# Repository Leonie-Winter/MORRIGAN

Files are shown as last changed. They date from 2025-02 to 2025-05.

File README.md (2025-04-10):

# MORRIGAN
--- 
## What is Morrigan?

Morrigan stands for 
- **M**obile
- **O**ptimized
- **R**eal-time
- **R**essource 
- **I**nterface
- **G**auge
- **A**nalysis
- **N**etwork

and aims to be a simple-to-use device based on the Raspberry Pi 3 to determine the quality of water using sensors from Gravity.

It measures the `total dissolved solids (TDS)(that are conductive), the dissolved oxygen (DO), the temperature, the pH, and the Turbidity`

---
You will find a build log in the [wiki](https://github.com/Leonie-Winter/MORRIGAN/wiki/build_log)[WIP] to find out how to get started

`/src` includes all files for the actual code and `/models` which includes a custom pcb design and a 3d case

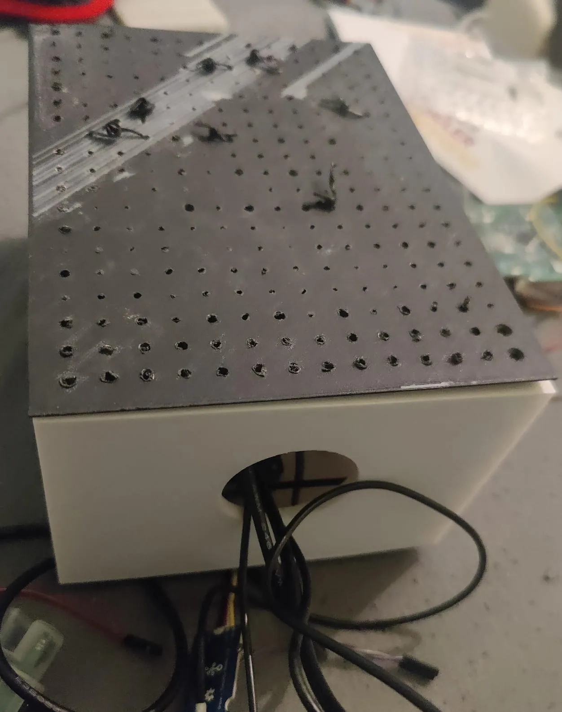
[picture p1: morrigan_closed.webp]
closed 3d shell
 &nbsp;&nbsp;&nbsp;&nbsp;&nbsp;
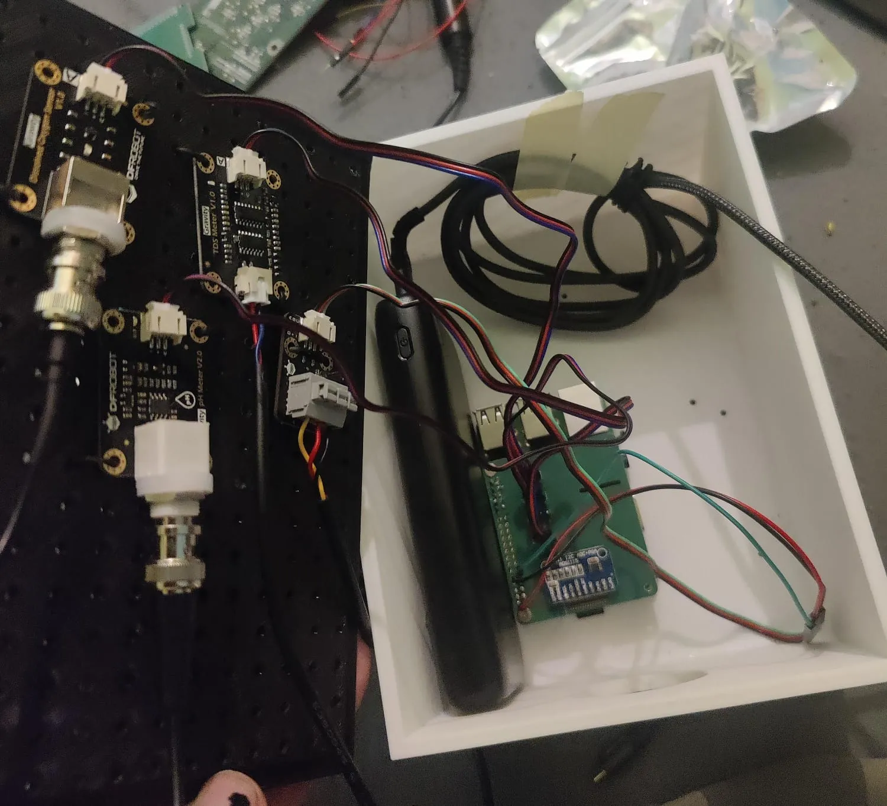
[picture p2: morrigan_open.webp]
open box showing some pcbs


--- 

If you are interested in thins such as previous competitions,the costs, and how it works check out the [wiki](https://github.com/Leonie-Winter/MORRIGAN/wiki/)

---

**This project was funded by the Erasmus+ program of the European Union.**
Funded by the European Union. Views and opinions expressed are however those of the author(s) only and do not necessarily reflect those of the European Union or the European Education and Culture Executive Agency (EACEA). Neither the European Union nor EACEA can be held responsible for them.
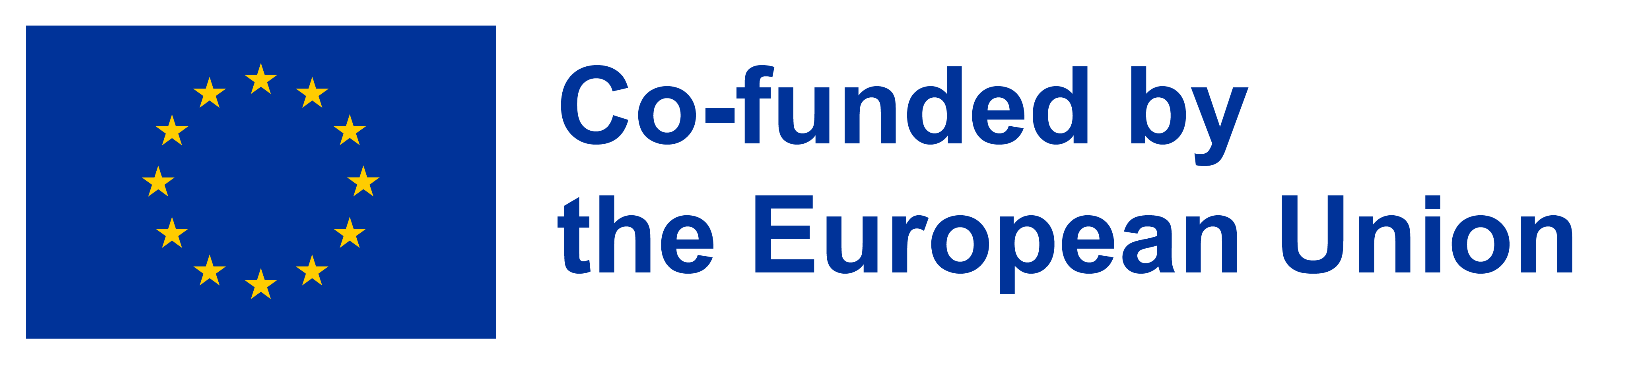
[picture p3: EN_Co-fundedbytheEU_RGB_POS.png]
co-funded by the european union logo


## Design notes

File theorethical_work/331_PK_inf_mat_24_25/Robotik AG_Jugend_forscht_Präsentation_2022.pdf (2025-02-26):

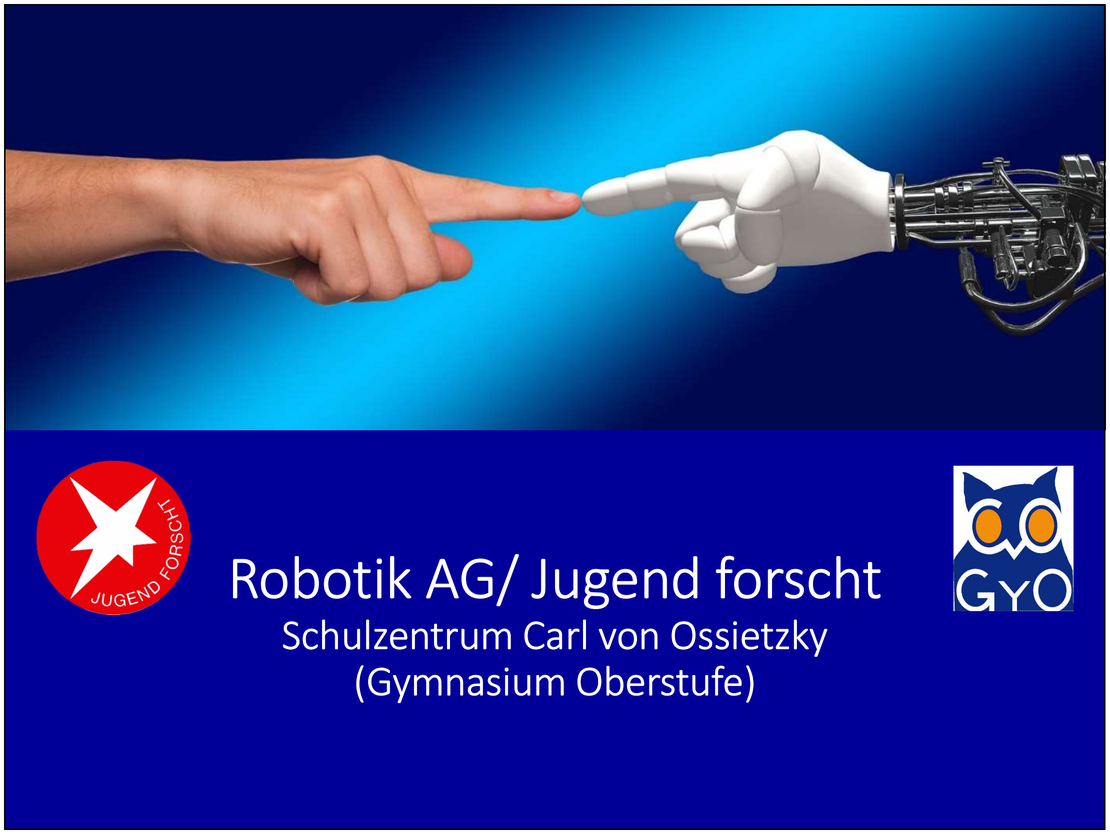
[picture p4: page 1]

Robotik AG am CvO | 03.09.2022 | Folie 1

## Robotik AG/ Jugend forscht

Schulzentrum Carl von Ossietzky (Gymnasium Oberstufe)

Robotik AG am CvO | 03.09.2022 | Folie 2

Robotik AG / Jugend forscht

## Wer wir sind

- ein erfahrenes Team, bestehend aus 3 KollegInnen
- Wir betreuen auch SchülerInnen beim Wettbewerb Jugend forscht bzw. Schüler experimentieren
- Die AG besteht seit 2010
- Sie findet freitags von 14:00 Uhr bis 17:30 statt

Kontakt:
Katja Pertlicsek: k.pertlicsek@schulen.bremerhaven.de Wolfram Bajus: w.bajus@schulen.bremerhaven.de

Wir sind auch über itslearning erreichbar!

Robotik AG am CvO | 03.09.2022 | Folie 3

Robotik AG

## Was wir anbieten

•Hilfe bei der Umsetzung eigener kleinerer technischer Projekte
•Unterstützung bei
der Planung, dem Bau, der Programmierung von Prototypen
technischen Projekten für Jugend forscht & Schüler experimentieren
•Arbeiten mit neuen Technologien 3D-Druckern, CNC-Portal-Fräsen
- Beratung und Erfahrungsaustausch

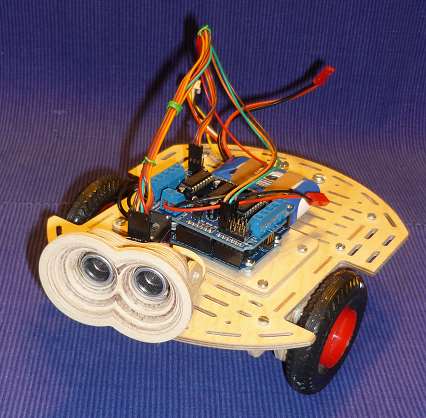
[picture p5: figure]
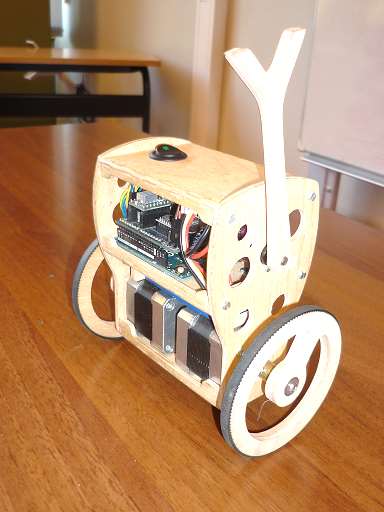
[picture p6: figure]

Robotik AG am CvO | 03.09.2022 | Folie 4

Robotik AG - Projektbeispiele

## Smartcars und balancierende Roboter

autonom fahrende,
Hindernis-vermeidende,
alternativ fernsteuerbare
Roboter

mit dem Smartphone
steuerbare Roboter

https://www.youtube.com/watch?v=ZSbpil-hHrE

## Laufroboter

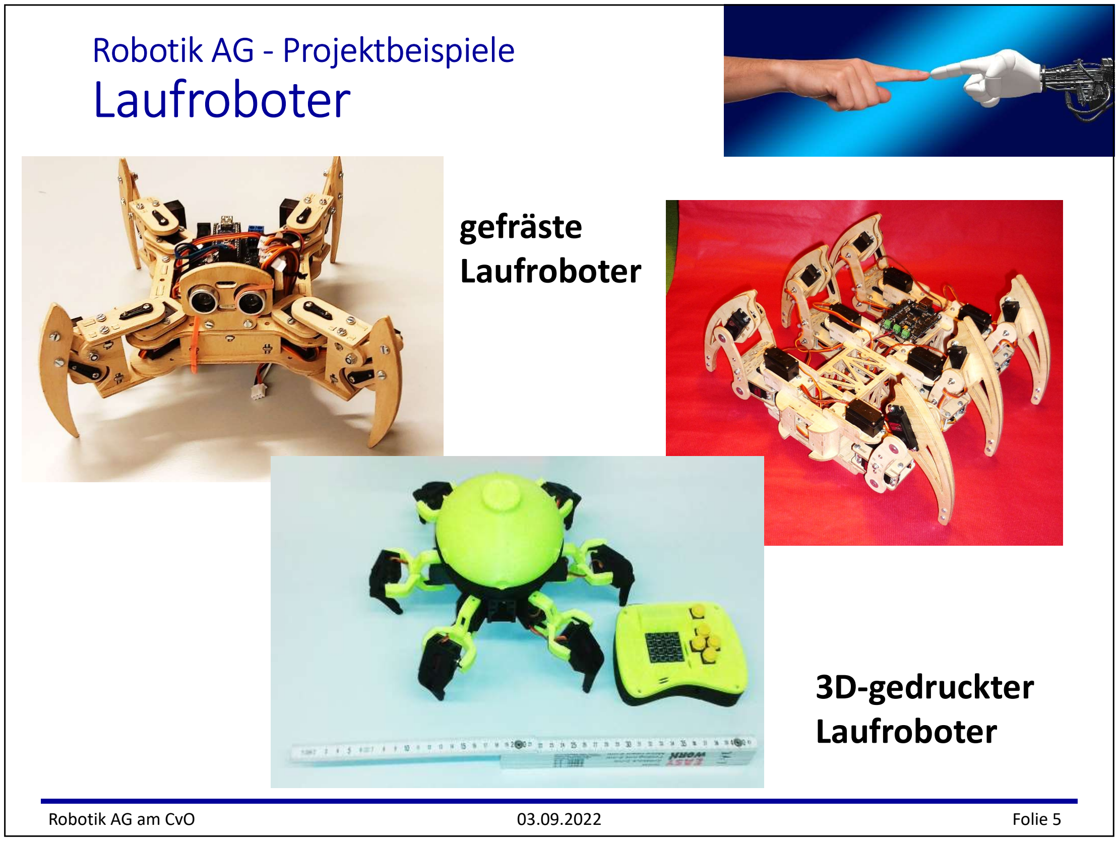
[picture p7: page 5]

Robotik AG am CvO | 03.09.2022 | Folie 5

Robotik AG - Projektbeispiele

gefräste
Laufroboter

3D-gedruckter
Laufroboter

## Ball balancierende Roboter

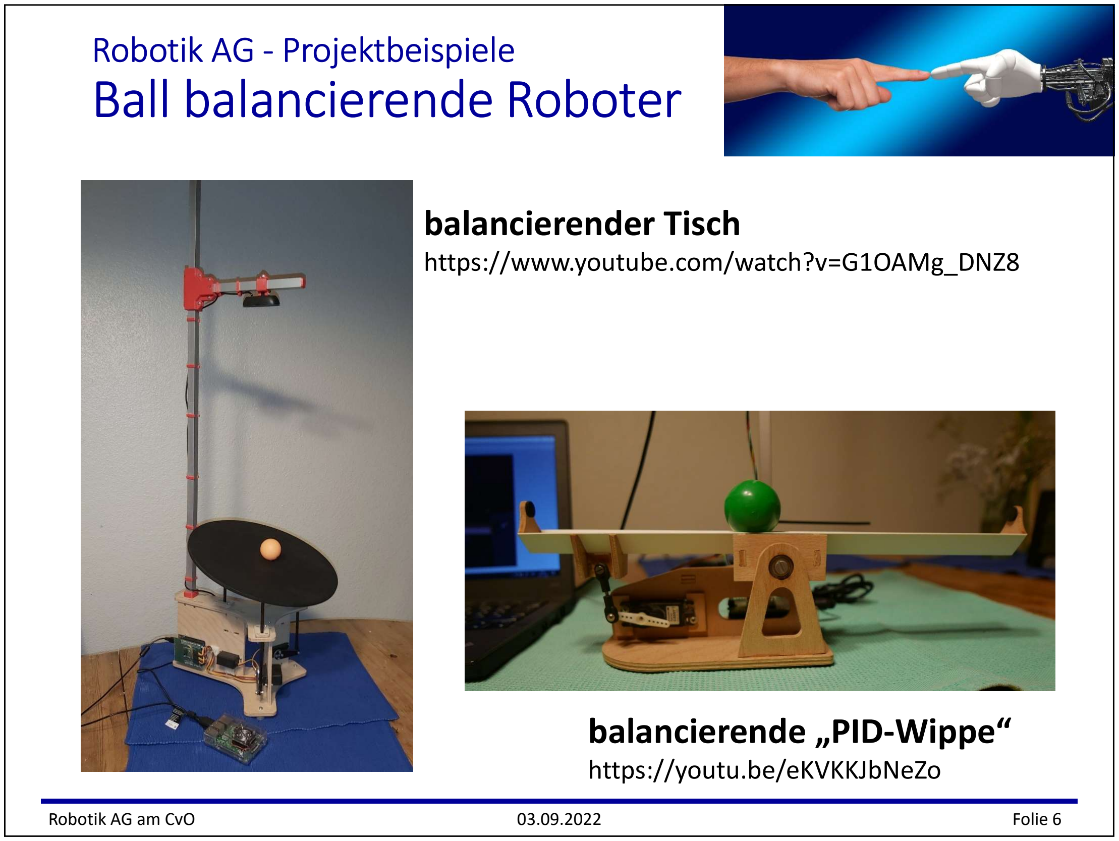
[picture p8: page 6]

Robotik AG am CvO | 03.09.2022 | Folie 6

Robotik AG - Projektbeispiele

balancierender Tisch
https://www.youtube.com/watch?v=G1OAMg_DNZ8

balancierende „PID-Wippe“
https://youtu.be/eKVKKJbNeZo

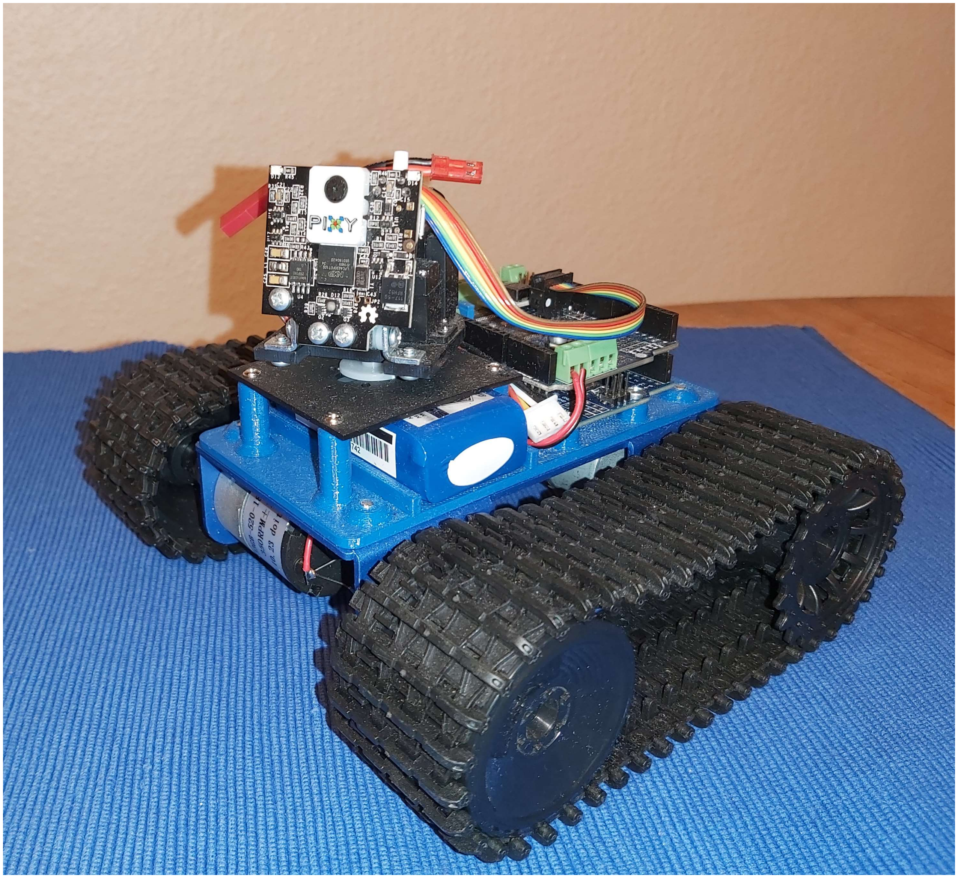
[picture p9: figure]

Robotik AG am CvO | 03.09.2022 | Folie 7

Robotik AG - Projektbeispiele

## Ball Chasing Robot

https://www.youtube.com/watch?v=rsmS00CuOFE

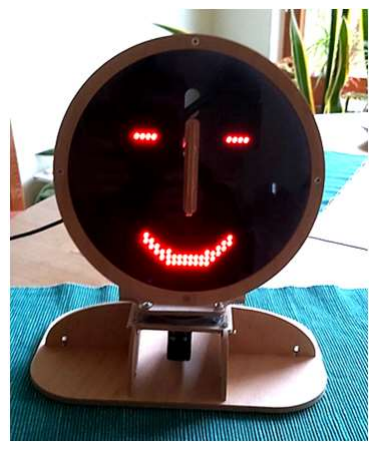
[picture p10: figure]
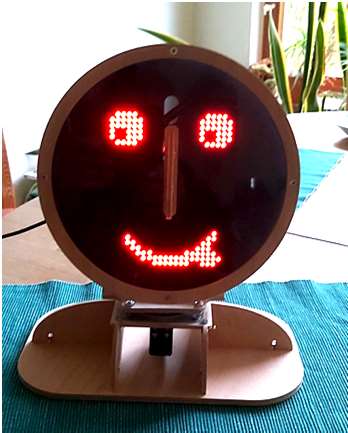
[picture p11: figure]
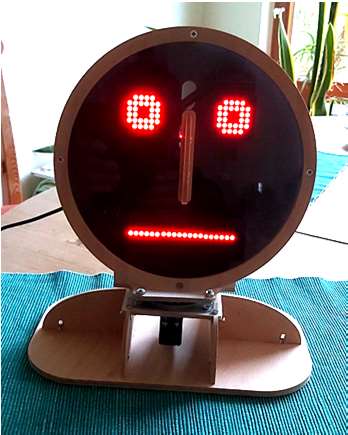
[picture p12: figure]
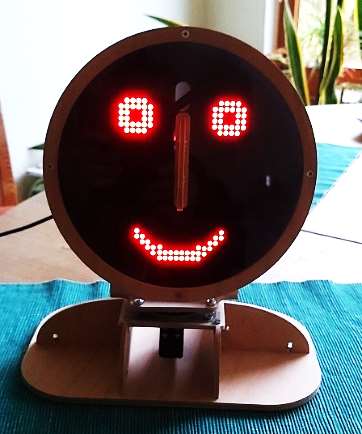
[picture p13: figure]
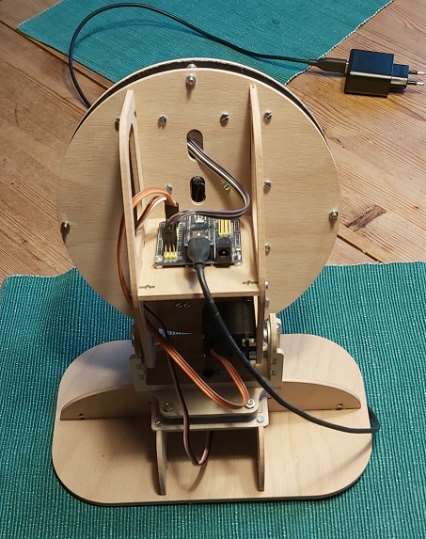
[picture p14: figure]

Robotik AG am CvO | 03.09.2022 | Folie 8

Robotik AG - Projektbeispiel

## Roboterkopf

Es braucht nur wenige Merkmale, damit wir Gesichter und
Emotionen darin erkennen.

Wenige Programmzeilen genügen, um dem Roboter neue
Gesichtsausdrücke beizubringen.

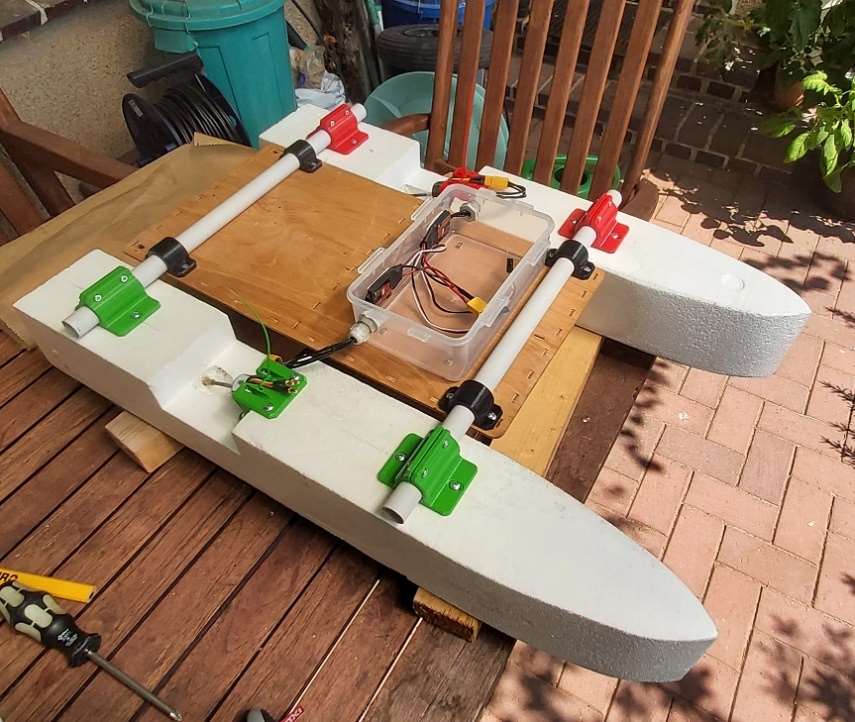
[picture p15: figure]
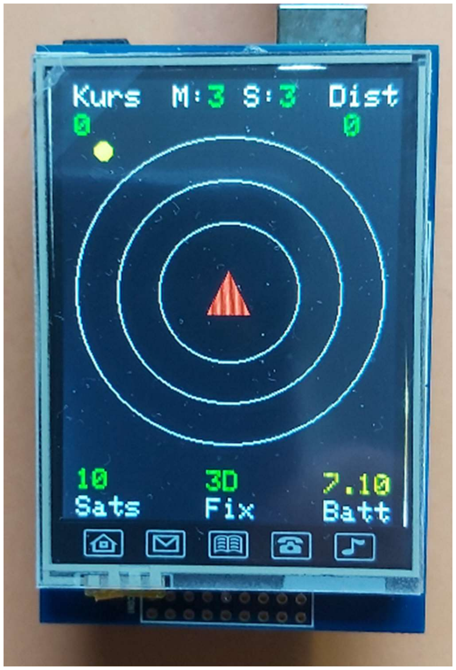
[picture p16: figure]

Robotik AG am CvO | 03.09.2022 | Folie 9

Robotik AG - Projektbeispiel

## Autonom fahrendes Boot

Testfahrt
https://www.youtube.com/watch?v=j5jiP22D6Fw&t=20s

Anzeige der
Telemetriedaten
Boot in der Bauphase

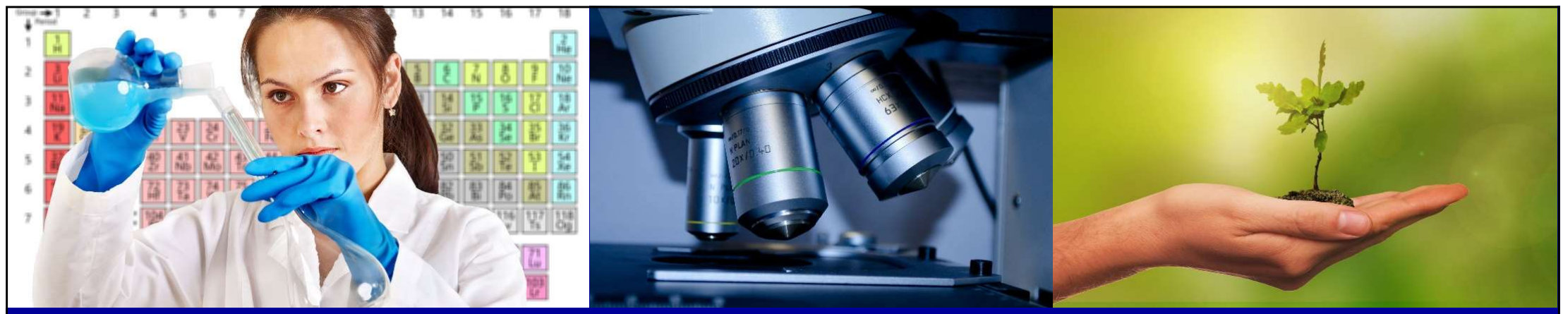
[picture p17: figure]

Robotik AG am CvO | 03.09.2022 | Folie 10

## Was Ihnen Jugend forscht anbietet

Robotik AG am CvO | 03.09.2022 | Folie 11

Jugend forscht Überblick

•Jugend forscht ist ein bundesweiter Nachwuchswettbewerb
- Hier starten Projekte, die mit naturwissenschaftlichen, technischen oder mathematischen Methoden arbeiten.
- Die vielfältigen Themen werden 7 Fachgebieten zugeordnet: Arbeitswelt, Biologie, Chemie, Geo- und Raumwissenschaften, Mathematik/Informatik, Physik, Technik
- Platzierungen erreichten wir seit 2019 in den Fachgebieten: Arbeitswelt, Biologie, Informatik, Physik und Technik

Kontakt:
Katja Pertlicsek: k.pertlicsek@schulen.bremerhaven.de

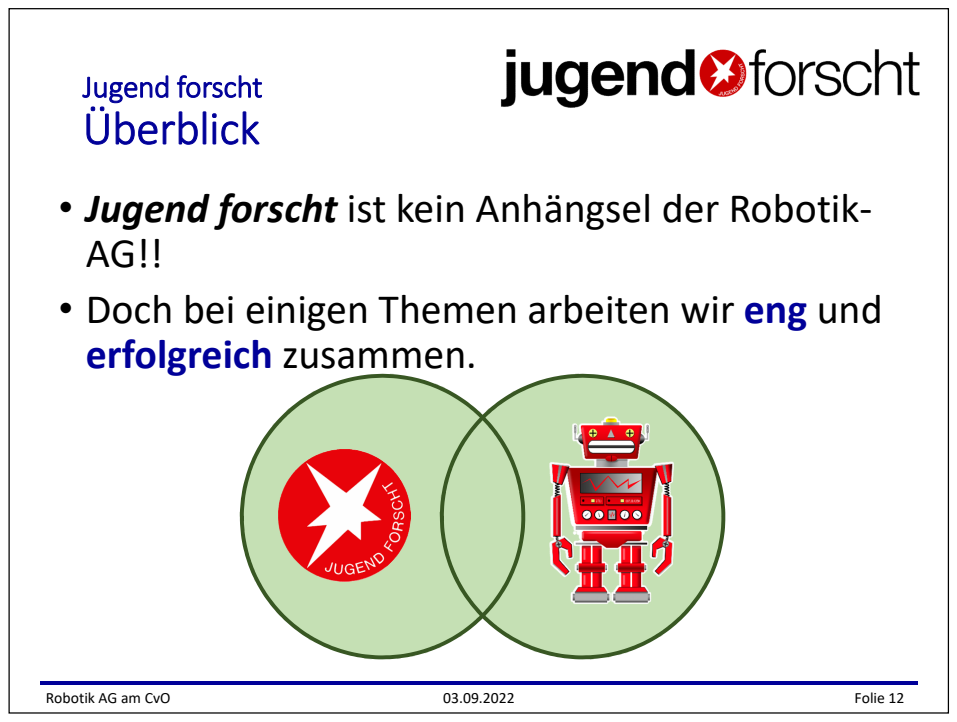
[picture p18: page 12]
Robotik AG am CvO; Folie 12

Jugend forscht Überblick

• Jugend forscht ist kein Anhängsel der Robotik-
• Doch bei einigen Themen arbeiten wir eng und
erfolgreich zusammen.

## Freifall-Schokolinsen-Sortiermaschine

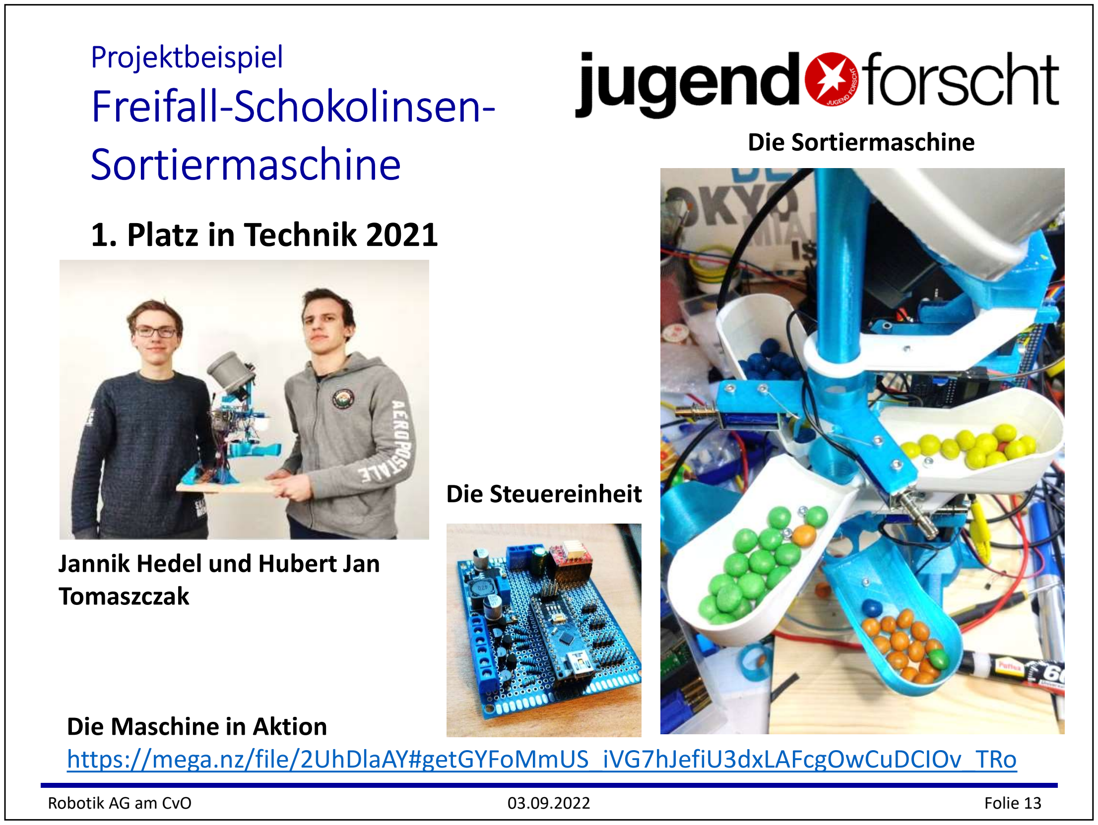
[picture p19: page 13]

Robotik AG am CvO | 03.09.2022 | Folie 13

Projektbeispiel

Die Maschine in Aktion
https://mega.nz/file/2UhDlaAY#getGYFoMmUS_iVG7hJefiU3dxLAFcgOwCuDCIOv_TRo

Jannik Hedel und Hubert Jan Tomaszczak

### 1. Platz in Technik 2021

Die Sortiermaschine

Die Steuereinheit

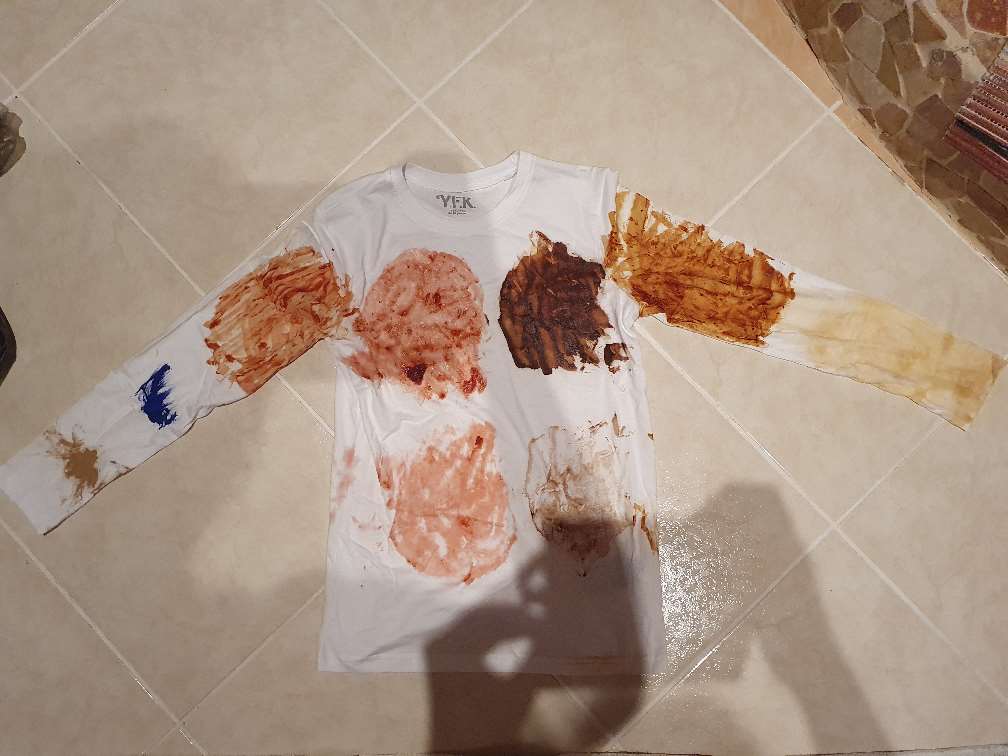
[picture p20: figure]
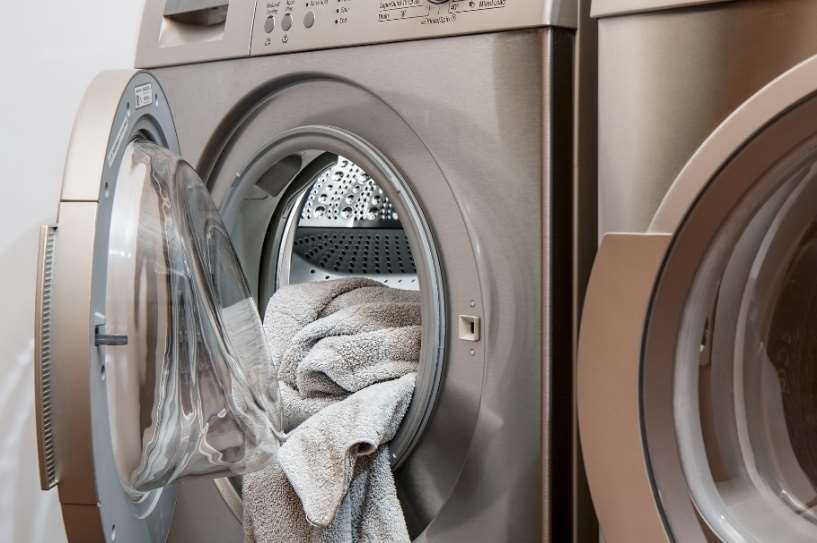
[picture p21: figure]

Robotik AG am CvO | 03.09.2022 | Folie 14

Aktuelle Projekte
Wie gut sind
herkömmliche Waschmittel?
Waschmittel-Hersteller suggerieren,
- ihre Waschmittel wären die besten
- damit gewaschen, die Wäsche wie neu aussähe
Berat Özel und Acelya Erkin testen …
- die Waschkraft
verschiedener Waschmittel
- an auf die gleiche Weise verschmutzen T-Shirts
- und überprüfen nach dem
Waschen die Sauberkeit.

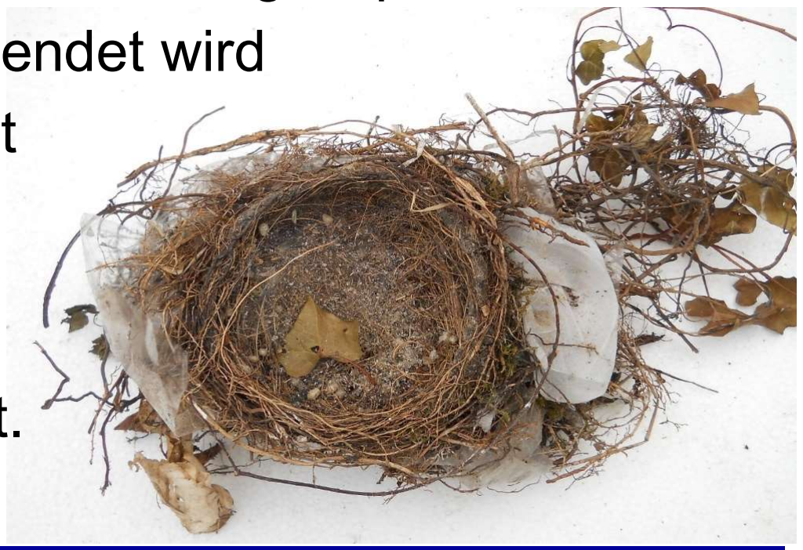
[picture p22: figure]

Robotik AG am CvO | 03.09.2022 | Folie 15

Aktuelle Projekte
Vogelnester auf Plastik
untersuchen

Leonie Sophie Prigge hat entdeckt, dass …. Vogelnester Plastikreste enthalten
Sie will daher klären, ….
- welche Rolle Plastik im Leben der Vögel spielt
- wie viel beim Nestbau verwendet wird
- wie der Verbreitungsgrad ist

Dafür hat sie viele Nester an unterschiedlichsten Orten
eingesammelt und untersucht.

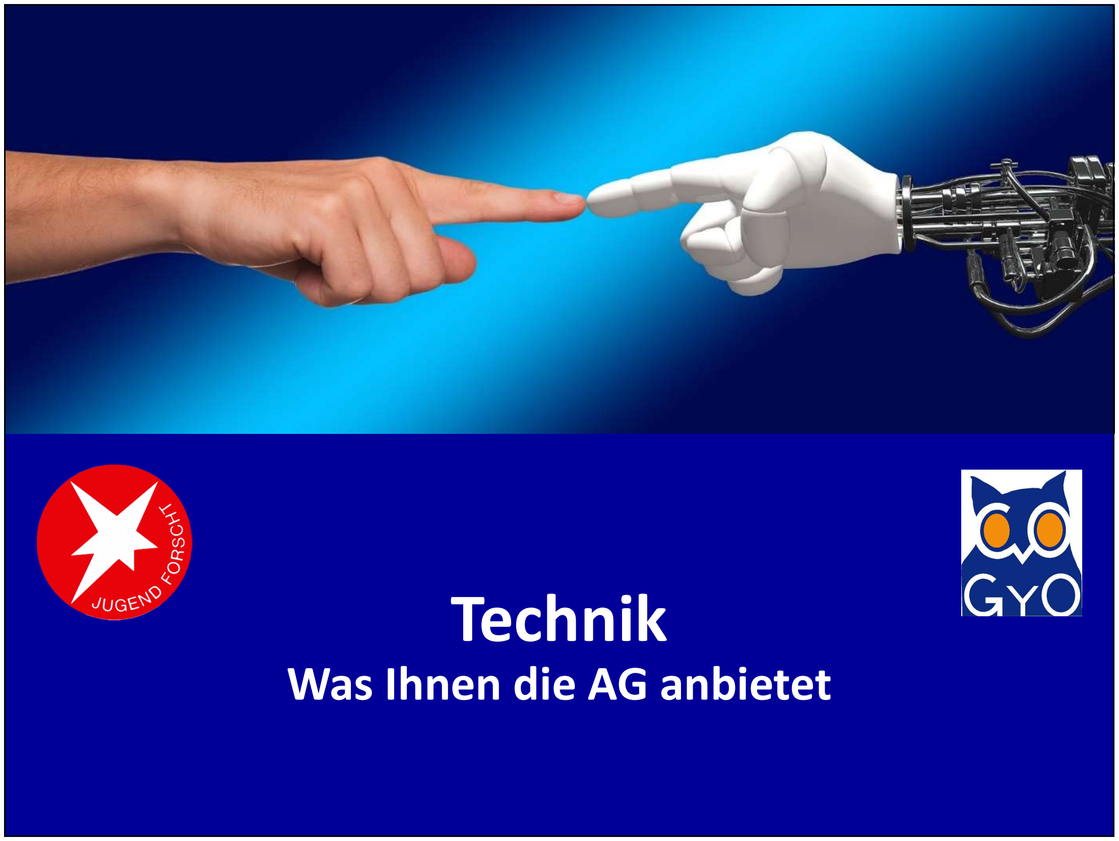
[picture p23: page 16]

Robotik AG am CvO | 03.09.2022 | Folie 16

# Technik

## Was Ihnen die AG anbietet

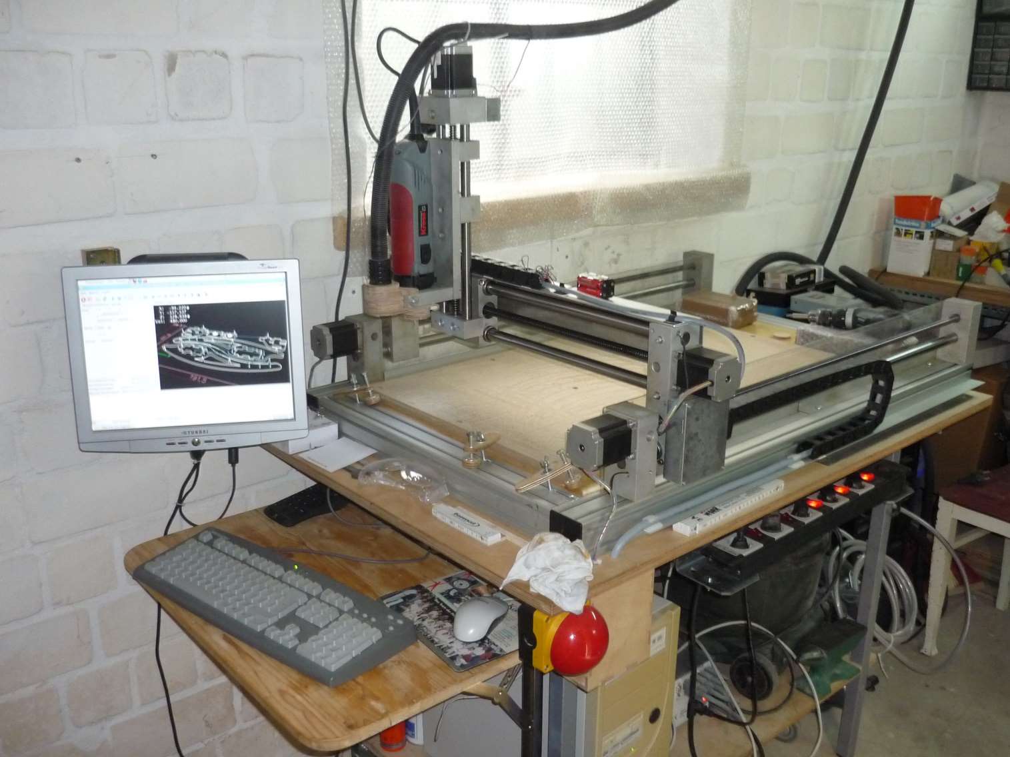
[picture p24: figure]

Robotik AG am CvO | 03.09.2022 | Folie 17

Von der Idee zum Produkt

## Eine CNC-Portalfräse

- Fertigung
mit einer
CNC-Fräse

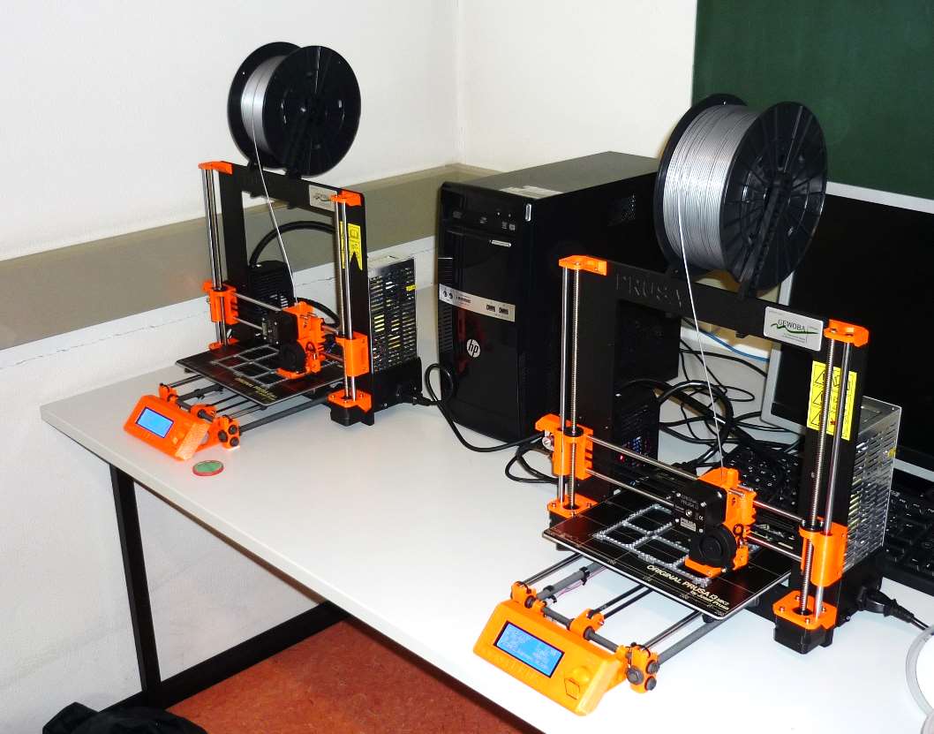
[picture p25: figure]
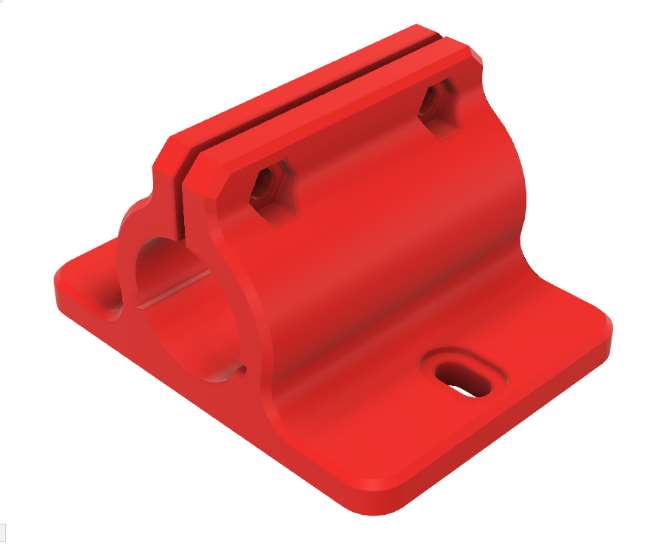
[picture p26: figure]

Robotik AG am CvO | 03.09.2022 | Folie 18

Von der Idee zum Produkt

## Gedruckt auf einem 3D-Drucker

Zwei von unseren 3 Prusa 3D-Druckern

Klemme für das
autonom fahrende Boot

Robotik AG am CvO | 03.09.2022 | Folie 19
- Wenn Sie Fragen haben, dürfen Sie uns gerne kontaktieren.
- Wir freuen uns auf Ihre Nachfragen.

Robotik AG / Jugend forscht

# Kontakt

Kontakt:
Katja Pertlicsek: k.pertlicsek@schulen.bremerhaven.de Wolfram Bajus: w.bajus@schulen.bremerhaven.de

Wir sind auch über itslearning erreichbar!

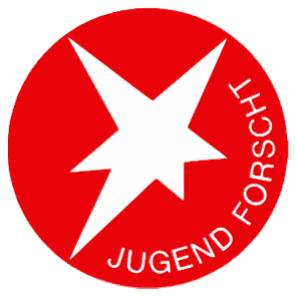
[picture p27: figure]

Robotik AG am CvO | 03.09.2022 | Folie 20

## Robotik AG / Jugend forscht

## Vielen Dank für Ihre Aufmerksamkeit!

Bildnachweis:
Alle Fotos von den Projekten sind eigene Fotos.
Die Fotos vom Jugend forscht Projekt sind Eigentum von Hedel & Tomaszczak. Alle anderen Fotos Pixabay (lizenzfrei) / Jugend forscht Banner (Wikipedia)

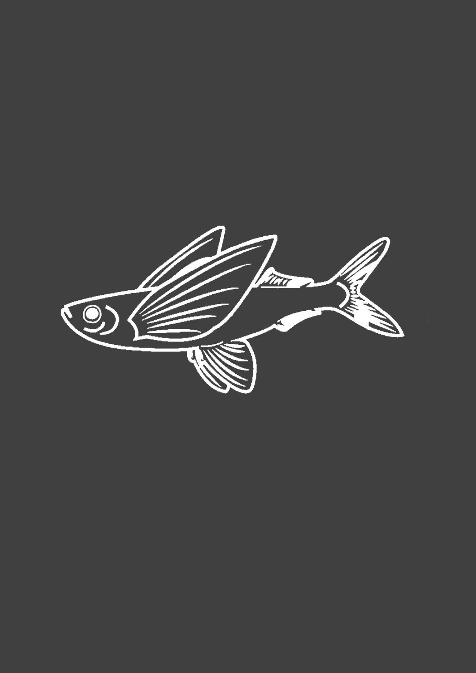
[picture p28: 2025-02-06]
theorethical_work/figures/poster_figures/white_flyingfish_simple_r.png

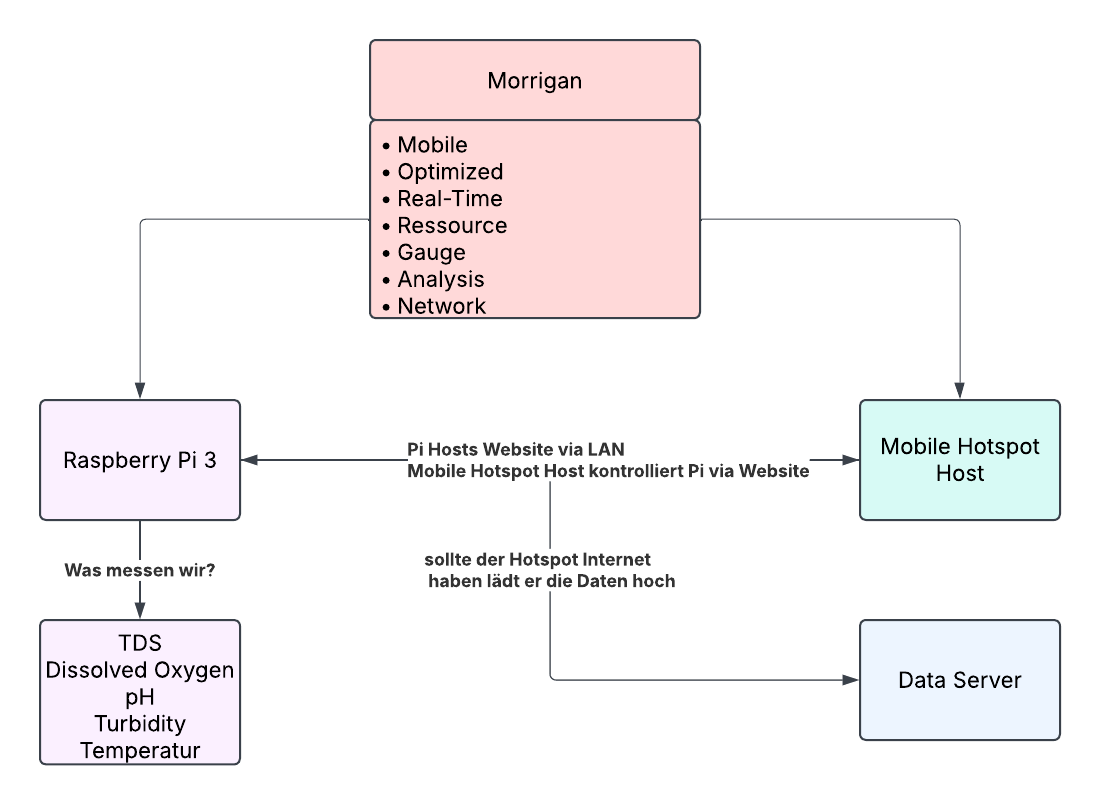
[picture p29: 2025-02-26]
theorethical_work/figures/MORRIGAN_figures/figure_2_concept_of_communication.png

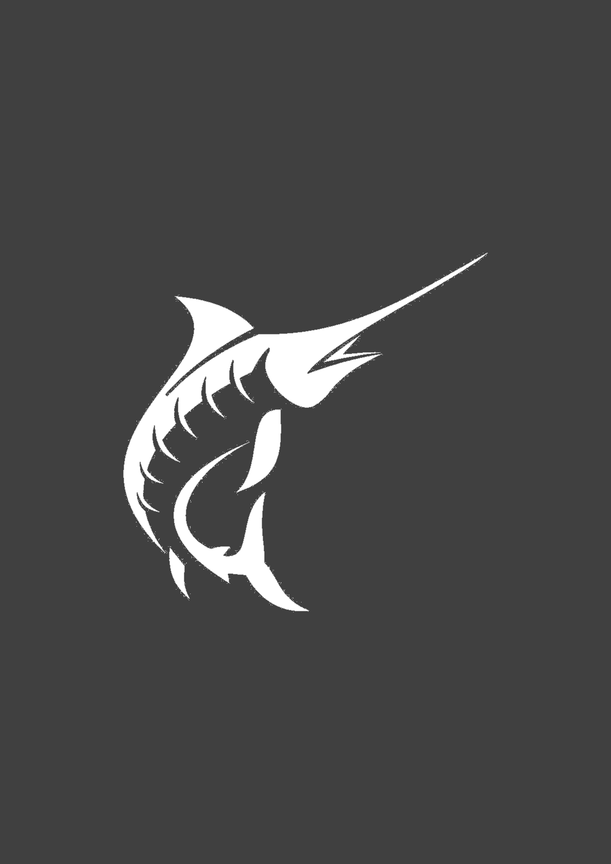
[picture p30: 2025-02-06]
theorethical_work/figures/poster_figures/white_swordfish_simple_l.png

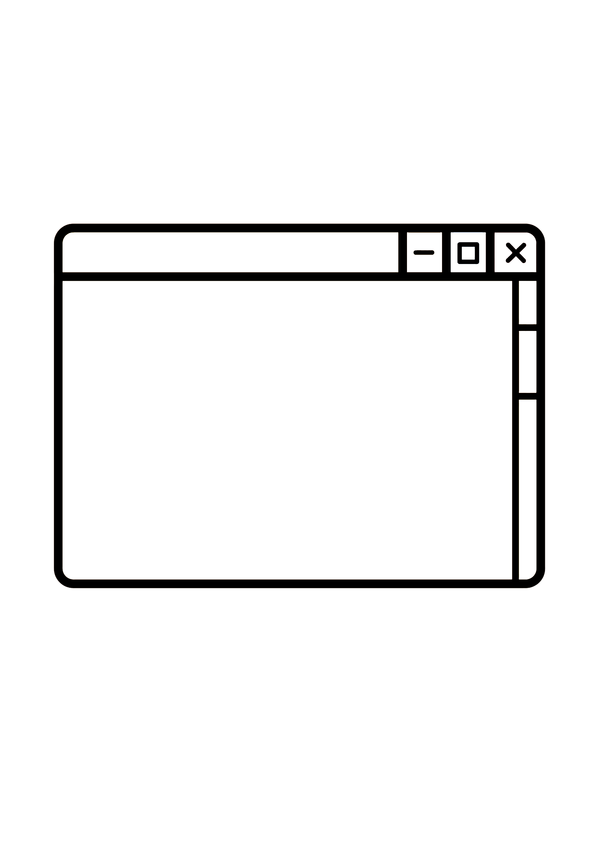
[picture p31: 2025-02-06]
theorethical_work/figures/poster_figures/simple_browser.png

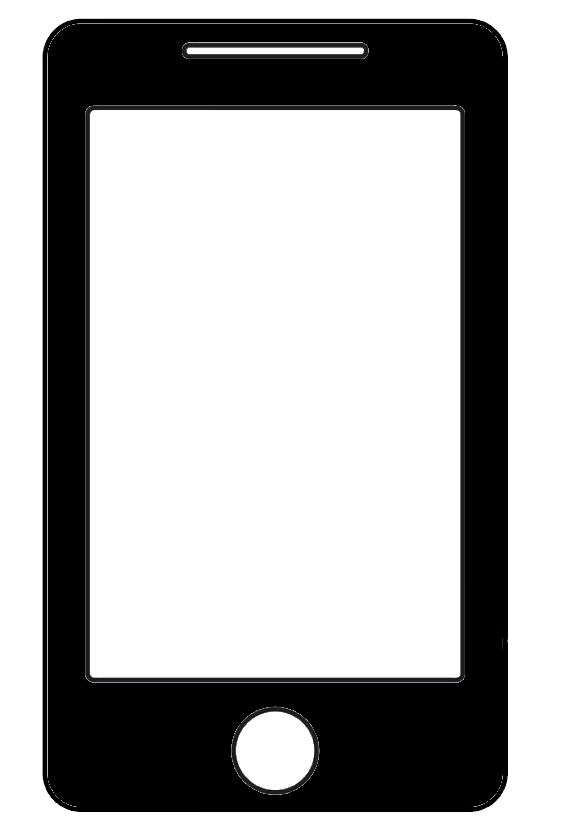
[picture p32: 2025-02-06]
theorethical_work/figures/poster_figures/simple_phone.png

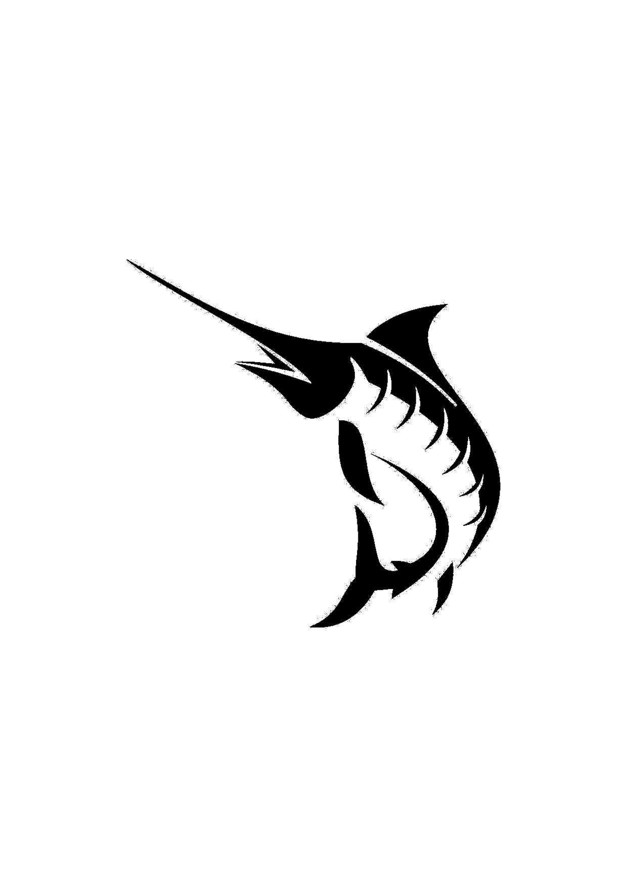
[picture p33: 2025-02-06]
theorethical_work/figures/poster_figures/black_swordfish_simple.png

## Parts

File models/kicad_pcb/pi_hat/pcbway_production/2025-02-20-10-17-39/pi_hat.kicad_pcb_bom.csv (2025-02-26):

Designator | Quantity | Value | Footprint | Package | MPN | DNP | Mount_Type
A1, A2, A3, A4 | 4 | ~ | analog_Pins |  |  |  | tht
J1 | 1 | GPIO | PinSocket_2x20_P2.54mm_Vertical |  |  |  | tht
U2 | 1 | ~ | ADS1115 |  |  |  | tht

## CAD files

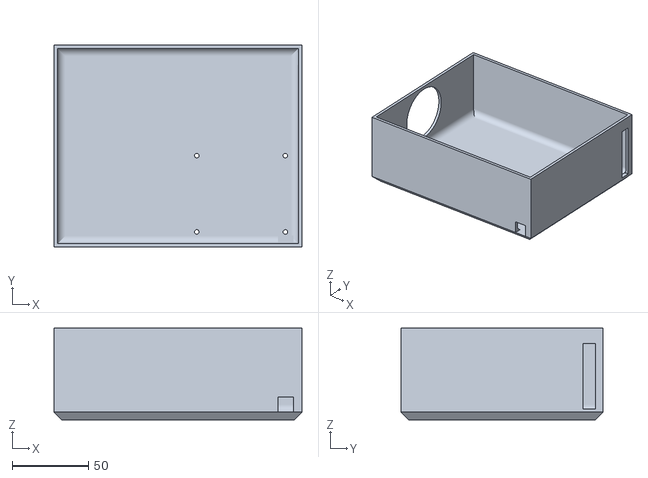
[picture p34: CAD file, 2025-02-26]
models/3D_modell/Body.stl
162.4 x 132.4 x 60.0

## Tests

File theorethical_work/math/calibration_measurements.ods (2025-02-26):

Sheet: Dissolved Oxygen
Temperature [°C] | Voltage [V] | Lineare Regression |  | t [°C] | O2 [%] | U [V] |  |  | T[K] | Salinität | 100% O2-Sättigung Wert [mg/L] nach Benson & Krause | Messung 2 | U[V] | O2[mg/L]
16,125 | 1,61025 | 0,0466607142857143 | 0,863685267857143 | 21,5 | 100 | 1,865 | 0,01829 | 0,0359999999999999 | 294,65 | 0 | 8,82861492785682 | BEG Zentralkläranlage | 2,0085 | 18,4
15,125 | 1,570875 | 0,00151543925066265 | 0,020809430617138 | 21,5 | 0 | 0,036 | 0 | 0 | 294,65 | 0 |  | 2025-02-18 | 1,80125 | 16,6
14,125 | 1,5305 | 0,995798486620948 | 0,00633953721835096 |  |  |  | 1 | 0 |  |  |  | VE Wasser mit Natriumsulfit | 1,747 | 16,2
13,125 | 1,47375 | 948,037906137188 | 4 |  |  |  | #NV | 0 |  |  |  |  | 1,654 | 14,9
12,125 | 1,434375 | 0,0381013895089286 | 0,000160758928571428 |  |  |  | 1,6726205 | 0 |  |  |  | ROH | 1,5395 | 14
11,125 | 1,376875 |  |  | Leitungswasser | U [V] | O2 [%] |  |  |  |  |  | DO | 1,451625 | 13,1
 |  |  |  | 21,5 | 1,3 | 35,1111111111112 |  |  |  |  |  | 18.4 | 0,37225 | 1,7
 |  |  |  |  |  |  |  |  |  |  |  | Analog value: 16067 | 0,108875 | 0,3
 |  |  |  |  |  |  |  |  |  |  |  | Voltage: 2.0085V
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

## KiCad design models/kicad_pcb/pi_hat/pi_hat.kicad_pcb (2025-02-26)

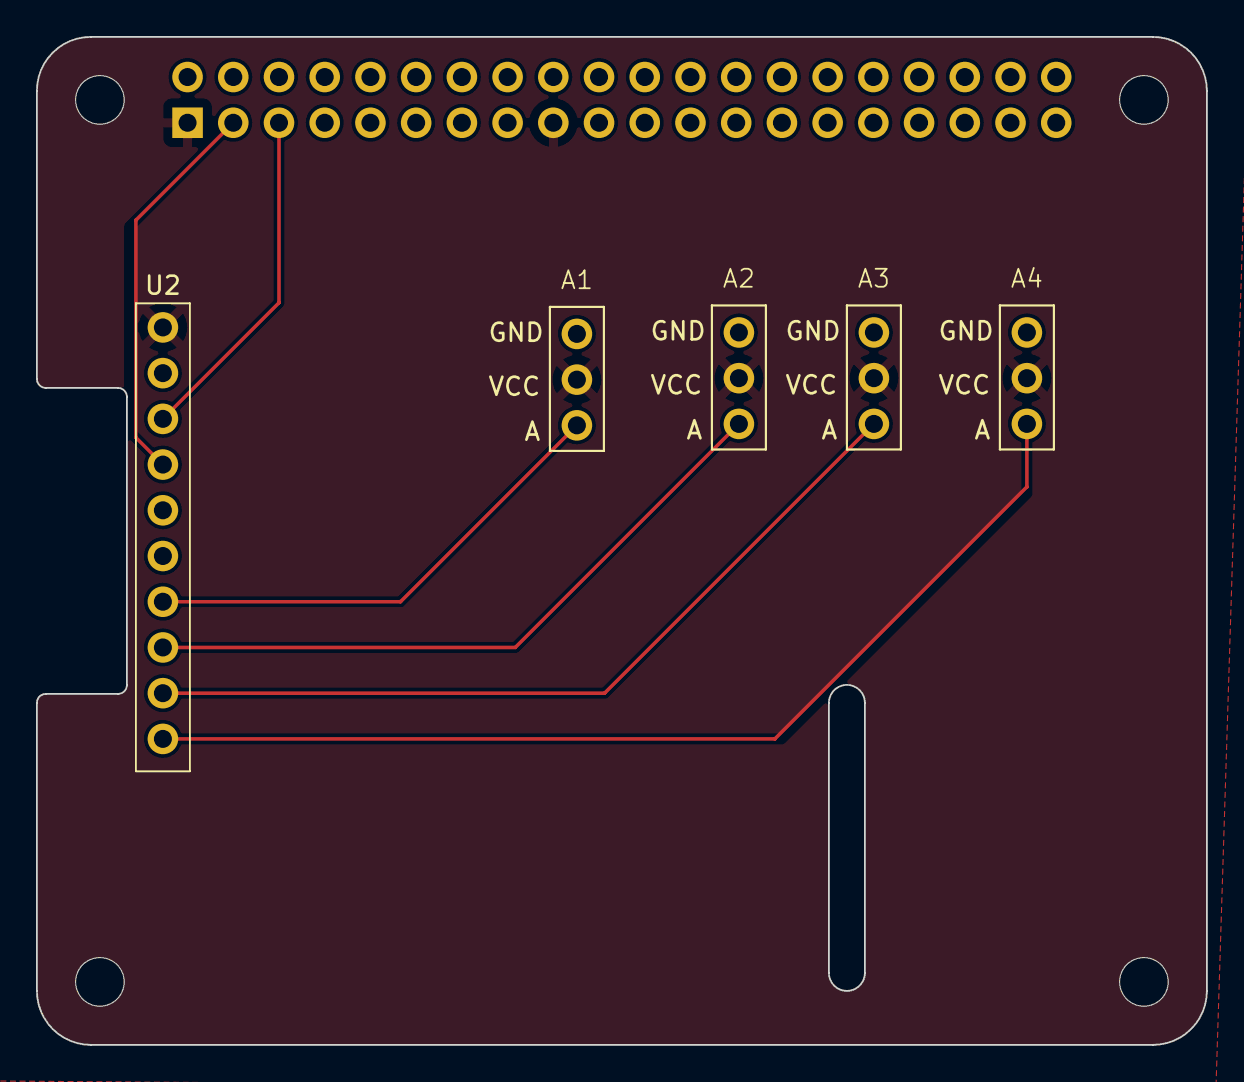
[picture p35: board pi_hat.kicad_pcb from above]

Board: 2 copper layers, 65.0 x 56.0 mm, 10 parts (1 on the bottom side), 9 nets.

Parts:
A1, A2, A3, A4: analog_Pins
J1: GPIO; PinSocket_2x20_P2.54mm_Vertical
MH1, MH2, MH3, MH4: MountingHole_2.7mm_M2.5
U2: ADS1115

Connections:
+3V3: A1.2 (VCC), A2.2 (VCC), A3.2 (VCC), A4.2 (VCC), J1.1, J1.17, U2.1 (VDD)
+5V: J1.2, J1.4
/GPIO2/SDA1: J1.3, U2.4 (SDA)
/GPIO3/SCL1: J1.5, U2.3 (SCL)
GND: A1.1 (GND), A2.1 (GND), A3.1 (GND), A4.1 (GND), J1.6, J1.9, J1.14, J1.20, J1.25, J1.30, J1.34, J1.39, U2.2 (GND)
unnamed: A1.3 (A), U2.7 (A0)
unnamed: A2.3 (A), U2.8 (A1)
unnamed: A3.3 (A), U2.9 (A2)
unnamed: A4.3 (A), U2.10 (A3)

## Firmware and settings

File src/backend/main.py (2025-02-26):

from ph_read import *
from temp_read import *
from do_read import *
from tds_read import *
from turbidity_read import *
import board
import time
import busio
import adafruit_ads1x15.ads1115 as ADS
from adafruit_ads1x15.analog_in import AnalogIn
import os
import json
import sqlite3
from datetime import datetime

# Initialize I2C and ADS1115
i2c = busio.I2C(board.SCL, board.SDA)
ads = ADS.ADS1115(i2c, 0x08)

# Database setup
BASE_DIR = os.path.abspath(os.path.join(os.path.dirname(__file__), "..", "database"))
DB_PATH = os.path.join(BASE_DIR, "sensor_data.db")

def init_db():
    """Initialize the database and create table if it doesn't exist."""
    conn = sqlite3.connect(DB_PATH)
    cursor = conn.cursor()
    cursor.execute('''
        CREATE TABLE IF NOT EXISTS sensor_logs (
            id INTEGER PRIMARY KEY AUTOINCREMENT,
            timestamp TEXT,
            sensor TEXT,
            value REAL,
            voltage REAL,
            elapsed_seconds INTEGER
        )
    ''')
    conn.commit()
    conn.close()

init_db()  # init database

# Define sensor switching function 
def switch_sensor(sensor):
    return AnalogIn(ads, {"ph": ADS.P3, "TDS": ADS.P0, "turbidity": ADS.P1, "DO": ADS.P2}.get(sensor, ADS.P3))


# Initialize log variables
start_time = None 
log = []

BASE_DIR = os.path.abspath(os.path.join(os.path.dirname(__file__), "..", ".."))
DATA_FILE_PATH = os.path.join(BASE_DIR, "frontend", "charts", "data.json")

def log_data(sensor, value, voltage):
    ts, elapsed = datetime.now().isoformat(), int(time.time() - start_time)
    data = {"seconds": elapsed, "timestamp": ts, "voltage": voltage, sensor: value}
    json.dump(data, open(DATA_FILE_PATH, "w"), indent=4)

    with sqlite3.connect(DB_PATH) as conn:
        conn.execute("INSERT INTO sensor_logs VALUES (NULL, ?, ?, ?, ?, ?)", tuple(data.values()))

while True:
    temp = read_temp()
    log_data("temperature", temp, voltage=None)  
    
    ph_channel = switch_sensor("ph")
    ph_voltage = ph_channel.voltage
    ph_value = read_PH(ph_voltage)
    log_data("PH", ph_value, ph_voltage)
    time.sleep(1)

    TDS_channel = switch_sensor("TDS")
    TDS_voltage = TDS_channel.voltage
    EC_value = read_EC(TDS_voltage, temp)
    log_data("EC", EC_value, TDS_voltage)  
    TDS_value = read_tds(EC_value)
    log_data("TDS", TDS_value, TDS_voltage)
    time.sleep(1)

    turbidity_channel = switch_sensor("turbidity")
    turbidity_voltage = turbidity_channel.voltage
    turbidity_value = read_turbidity(turbidity_voltage)
    log_data("turbidity", turbidity_value, turbidity_voltage)
    time.sleep(1)

    DO_channel = switch_sensor("DO")
    DO_voltage = DO_channel.voltage
    DO_value = read_DO(DO_voltage,temp)
    log_data("DO", DO_value, DO_voltage)
    time.sleep(1)

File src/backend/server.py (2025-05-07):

from flask import Flask, jsonify, send_from_directory
from flask_cors import CORS
import subprocess
import os

app = Flask(__name__, static_folder="static")
CORS(app, resources={r"/run-script": {"origins": "*"}})

SCRIPT_PATH = os.path.join(os.path.dirname(__file__), "main.py")

@app.route('/')
def serve_index():
    return send_from_directory(app.static_folder, "index.html")

@app.route('/run-script', methods=['GET'])
def run_script():
    try:
        result = subprocess.run(f"python3 {SCRIPT_PATH}", capture_output=True, text=True, shell=True)
        return jsonify({"output": result.stdout.strip(), "error": result.stderr.strip()})
    except Exception as e:
        return jsonify({"error": str(e)}), 500

if __name__ == '__main__':
    app.run(host='0.0.0.0', port=5000, debug=True)

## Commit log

2025-02-08 Cleaned Repo, Fixed Code
    [main.py, ph_read.py, server.py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]
2025-02-09 fixed backend using pi
    [main.py, ph_read.py, tds_read.py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]
2025-02-09 jufo zeug
    [calibration_measurements.ods]
2025-02-20 cleaned repository and added sqlite
    [calibration_measurements.ods]
2025-02-25 Updated Temperature and Turbidity
    Updated Temperature and Turbidity Scripts to reflect new calibrations measurements
    [calibration_measurements.ods]
2025-02-26 added basically everything
    [Oxygen_Calculations.xlsx, Sauerstoffsensor_Kalibration_DFRobot.ods, calibration_measurements.ods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]
2025-02-26 3D Modell
    [Body.stl]
2025-04-02 moved theorethical
    [Body.stl, Oxygen_Calculations.xlsx, PK_Themen_2024.ods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]
